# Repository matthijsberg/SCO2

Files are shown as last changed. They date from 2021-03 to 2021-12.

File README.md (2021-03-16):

# SCO2
The SCO2 is a small scale personal initiative to create CO2 sensors for the school my kids go to. Goal is to make the sensor:
 - Easy to use for teachers and kids
 - Show details for those interested
 - Looks good draws attention when needed
 - Solid to survive the challenging school environment
 - Decent but relatively cheap to build

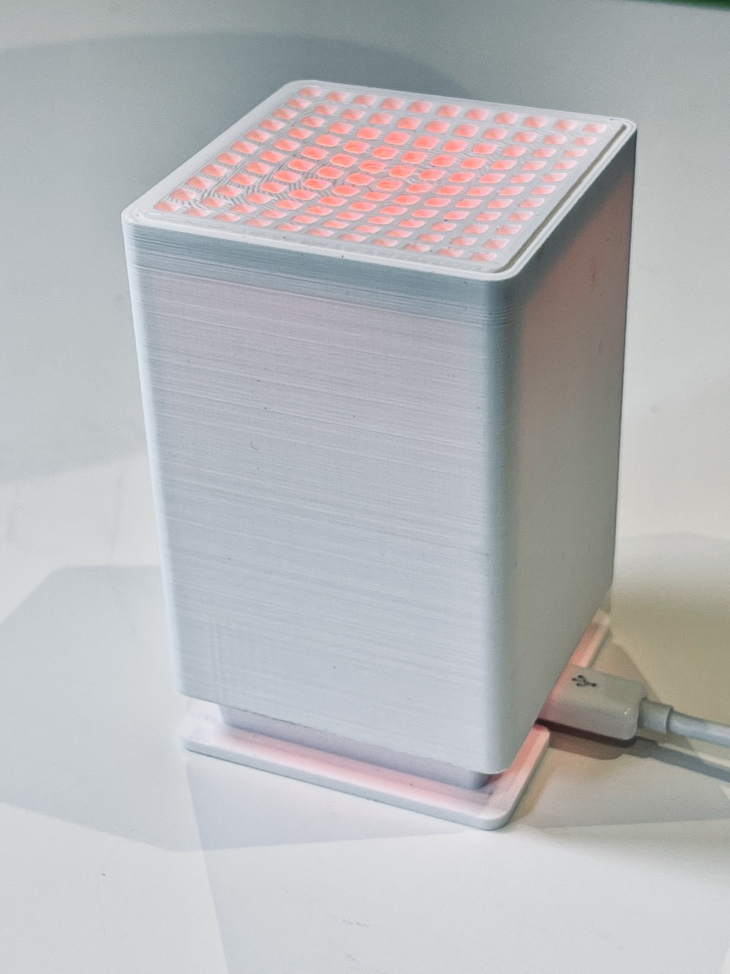
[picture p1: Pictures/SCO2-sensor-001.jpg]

 
# First Version
The first version is a completely home made device using some electronics, a soldering iron and a 3D printer (or an online 3D ordering service). 

## Components Used
The following components are used to build the sensor:
 - Wemos D1 Mini ESP board (this is the computer) https://www.wemos.cc/en/latest/d1/d1_mini.html
 - Sensirion SCD30 (This is the CO2 / Temp / Humidity sensor) https://www.sensirion.com/en/environmental-sensors/carbon-dioxide-sensors/carbon-dioxide-sensors-co2/
 - Wemos TGB Led Shield (to coler indicate air quality) https://www.wemos.cc/en/latest/d1_mini_shield/rgb_led.html
 - Some wires, shrinking tube and screws
 - 3D model existing out of 5 parts to put the sensor together. I fiddled around a bit with the tolerances to make the parts fit together nicely, so you might need to do so too. 

## Software used
I started out programming the thing myself in Visual code, that gives me great abilities but also is quite cumber stone since I'm not a programmer by trade. So I switched to ESPhome (https://esphome.io/). ESP Home abstracts the actual programming for you and all you need is a configuration file to tell the system what to compile for you. It can be ran alone or integrated into Home Assistant if you want an easy and comprehensive overview of all the sensors in for example your school. 

To be clear, the device can run alone without WiFi of back-end, but when you're up for it you can connect it and save the data in various systems. 

# 3D Files
The device exists out of 5 3D printer parts you can print on your own printer of via a service. You find the here, and assembling should be possible in one way only. :)

# Hardware assembly
Maybe I'll create a visual guide one day, but for now:
The hardware assembly consists out of 2 part, the D1 mini in the foot of the unit, and the sensor array holding the CO2 sensor and the LEDs. I build it like this so we can create new sensor array's later on and just swap them out. 

## ESP Board
This is the easy part, just solder a MALE pin header strip on the board ON ONE SIDE ONLY. We're only using the side of the board with the pin headers 5V to TX. once done, use 2 small screws to screw the board in the 3D printed bottom plate.

## Sensor Array
This is a bit trickier, since we need some wire and a couple of more connections. You need to:

 - 5V pin to 5V on the CO2 sensor and 5V on the LEDs
 - GND pin to GND on the CO2 sensor and GND on the LEDs
 - D4 on the board to D4 on the LEDs
 - D2 on the board to SDA on the CO2 sensor
 - D1 on the board to SCL on the CO2 sensor

# Software Installation
When you have all the parts in house and printed the enclosure make sure you have ESPHome running. For me it's part of my Home Assistant installation and for the school I build this for I have a Raspberry PI where I run HASSOS with ESP Home in. To get HASSIO running, please find the software and instructions here: https://www.home-assistant.io/installation/ . 

When you have ESPHome running as a Add-on:
 - Open the ESPHome interface
 - Connect the Device with a USB cable to your HA device
 - Open the "Secrets" File in the rop right corner to enter your passwords you will use (example in this github called secrets.yaml)
 - Create a new device, give it the right name straight away, but the rest of the information can be bogus IF you are using exactly the same ESP board
 - Now change the interface to upload the code to your device from over the air to the USB port (you can use OtA after initial flash)
 - Once created open the config by clicking "Edit" and past the example config from the repo into you config (sensor.yaml).
 - check if all the password and config options are correct and upload the file with "Upload"
 - See what happens. 
 - You can add the sensors to HA if you want under Integrations or under Device. 

Cheers! Drop me comments or improvements here in GitHub please. 

# Thank you!
 - Home Assistant for building great software that makes this easy to run a OS and a great Add-on ->
 - ESPHOME! This is amazing. Next gen programming language to make IOT easy IMHO. 
 - Autodesk for having a free edition of Fusion360
 - Ultimaker for providing the best slicer software for free to slice the 3D design and print them.

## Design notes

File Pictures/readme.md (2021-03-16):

Here are several picture of a finished sensor to give you an idea how to assemble it.

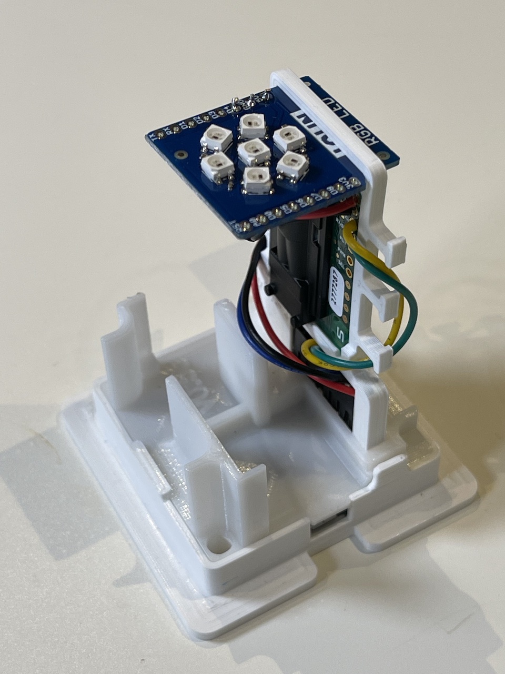
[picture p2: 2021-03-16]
Pictures/SCO2-sensor-008.jpg

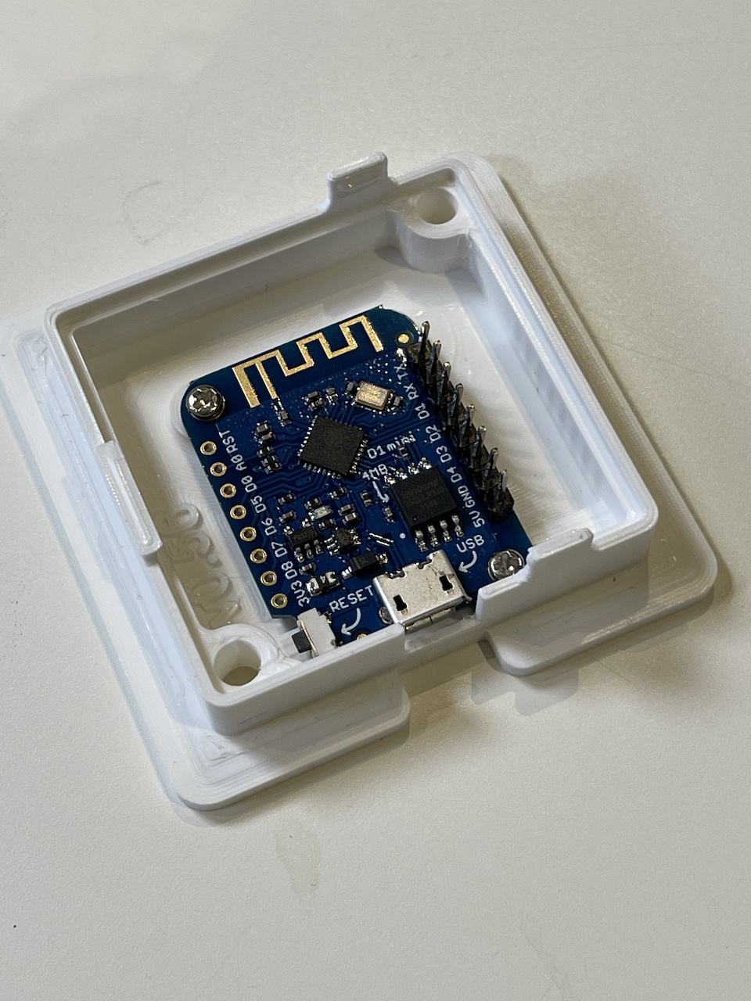
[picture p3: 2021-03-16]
Pictures/SCO2-sensor-004.jpg

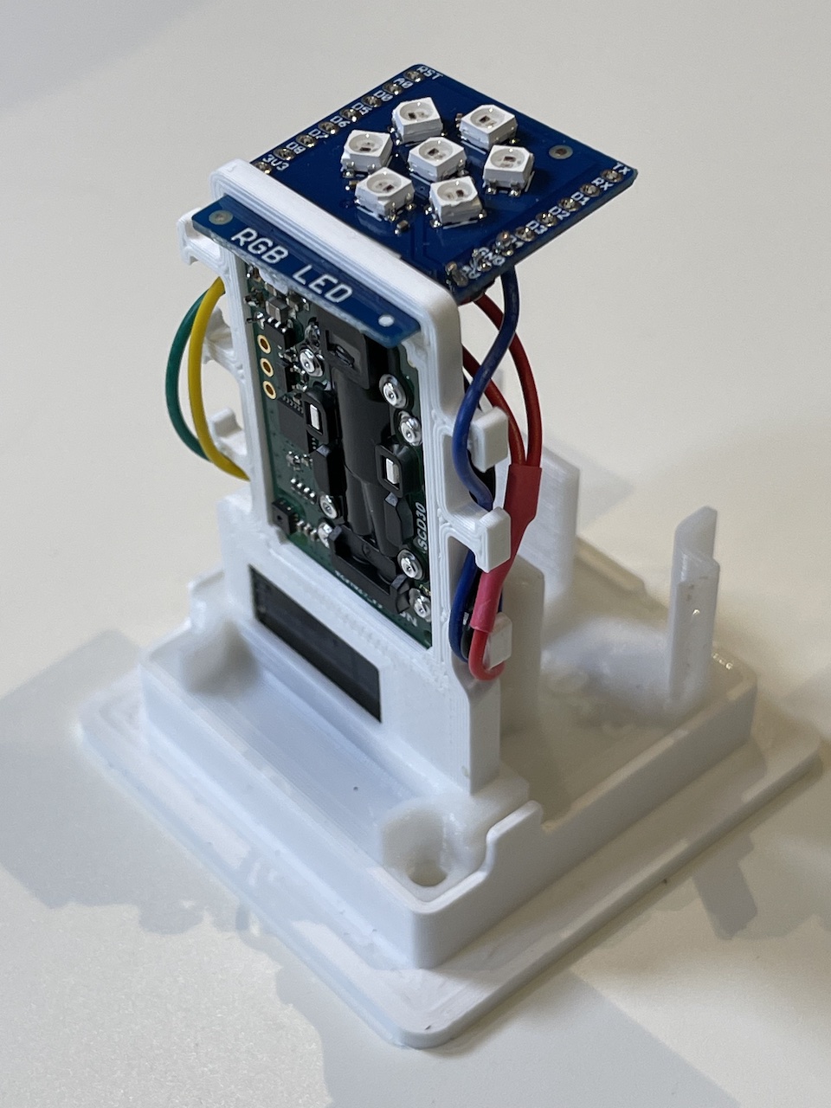
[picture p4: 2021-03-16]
Pictures/SCO2-sensor-007.jpg

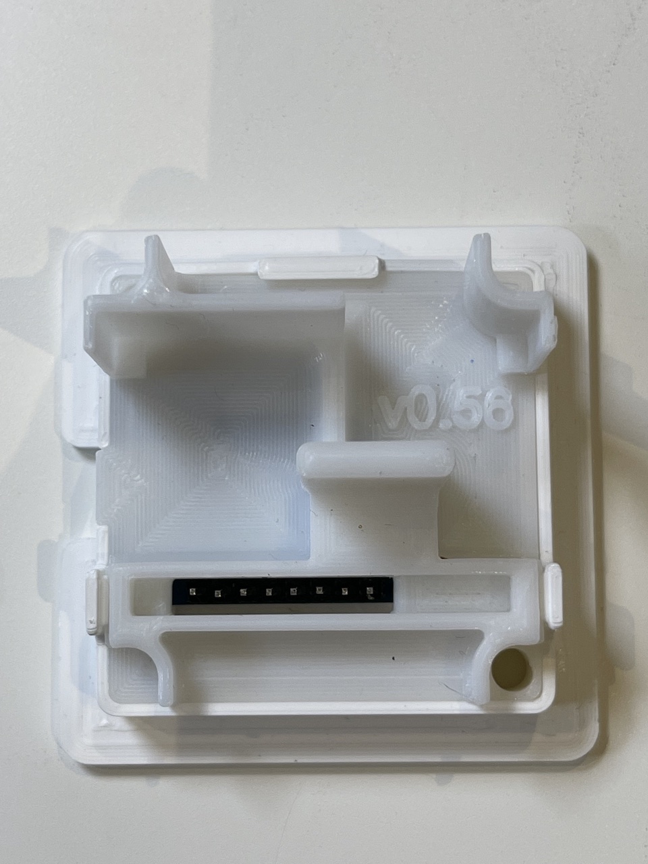
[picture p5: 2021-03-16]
Pictures/SCO2-sensor-005.jpg

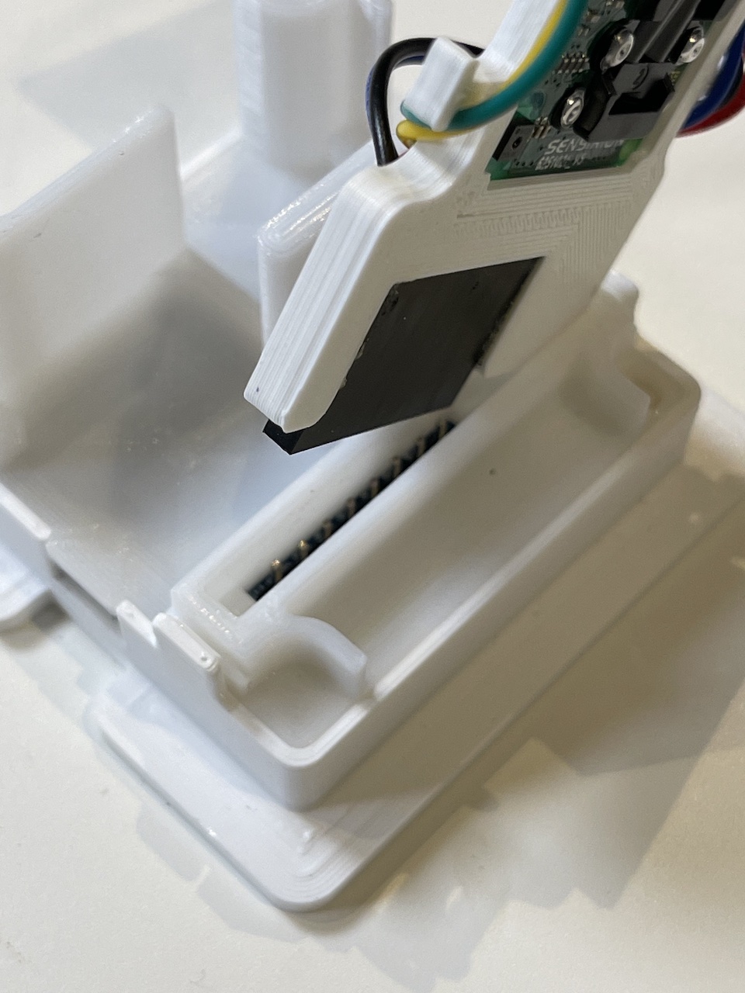
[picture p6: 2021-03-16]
Pictures/SCO2-sensor-003.jpg

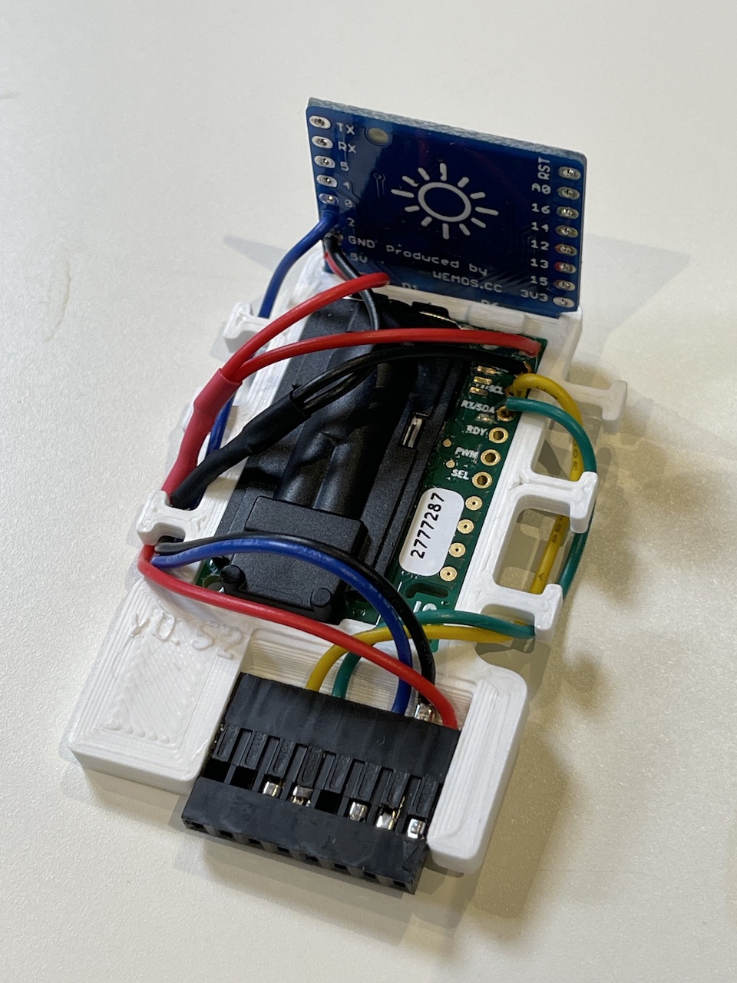
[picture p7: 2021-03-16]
Pictures/SCO2-sensor-006.jpg

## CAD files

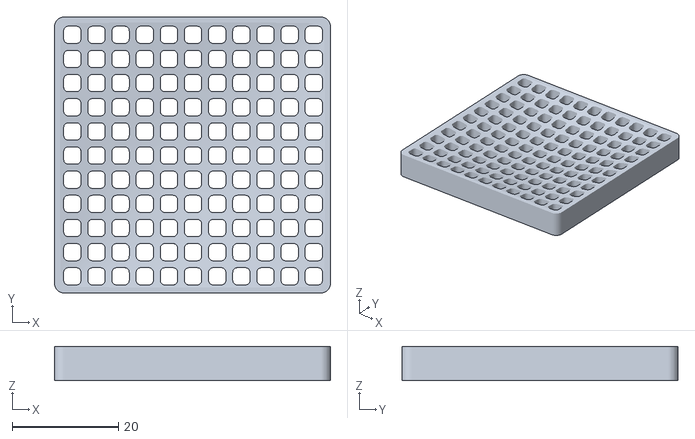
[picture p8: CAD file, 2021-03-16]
SCO2-TopGrid-v1.03.stl
51.8 x 51.8 x 6.47

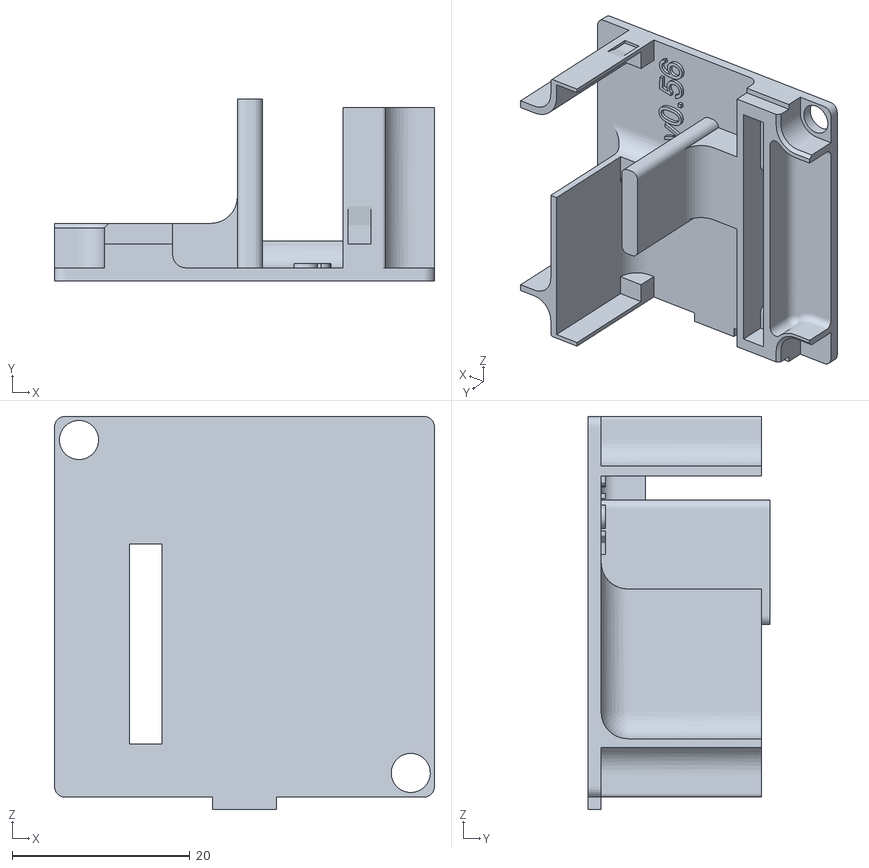
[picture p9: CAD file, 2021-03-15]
SCO2-BottomSensors-v1.02.stl
42.7 x 20.5 x 44.2

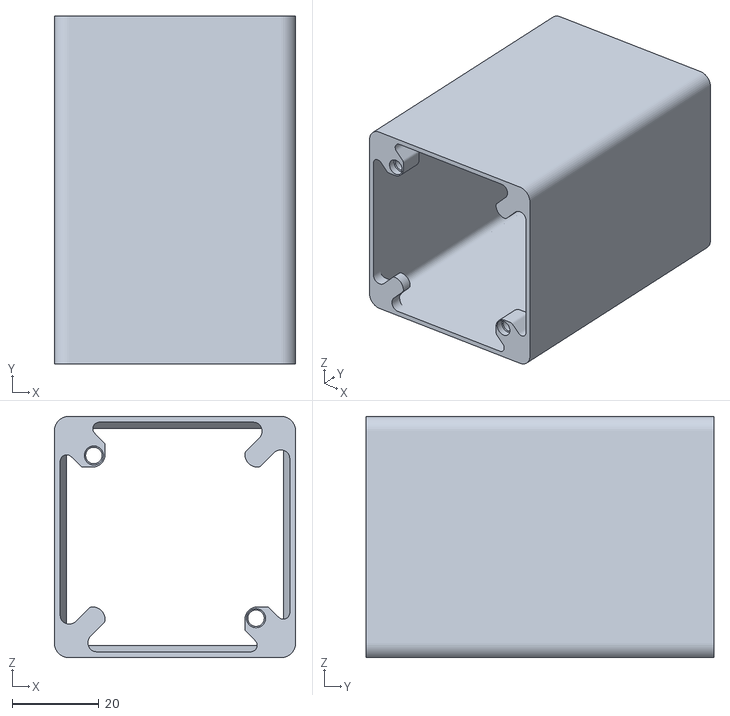
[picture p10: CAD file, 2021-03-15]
SCO2-Enclosure-v1.0.stl
55.5 x 80.0 x 55.5

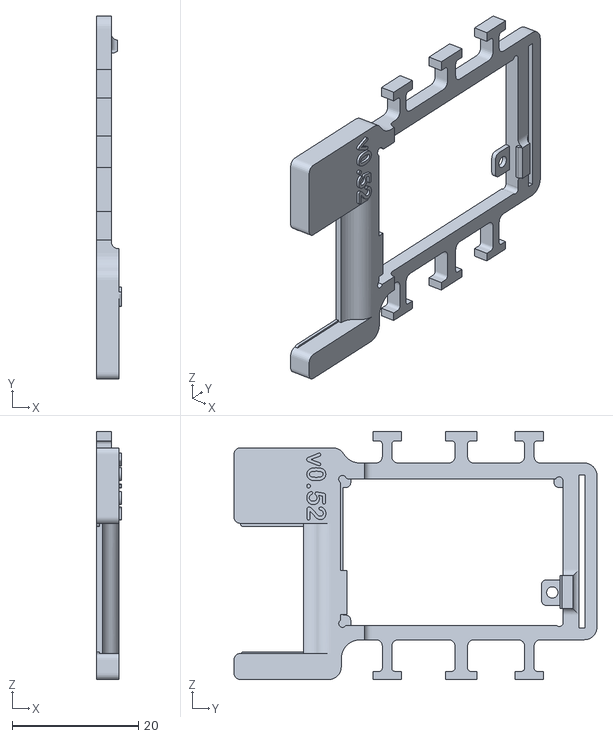
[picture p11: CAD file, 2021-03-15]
SCO2-SesorArray-v1.01.stl
3.90 x 57.5 x 39.3

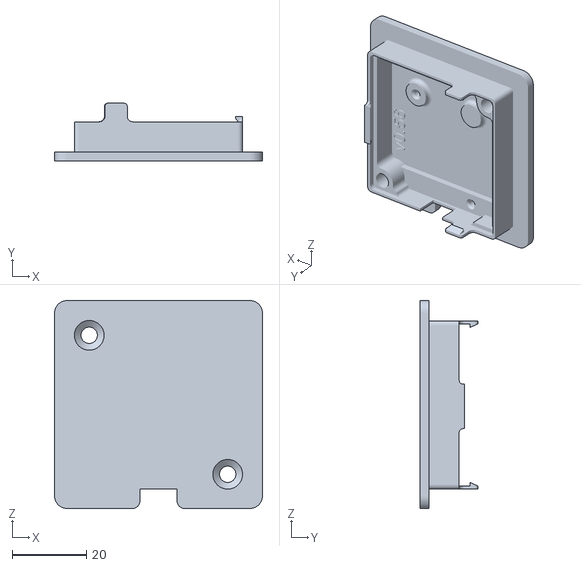
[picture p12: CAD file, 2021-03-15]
SCO2-BottomPlate-v1.01.stl
56.0 x 15.5 x 56.0

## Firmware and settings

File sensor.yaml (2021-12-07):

# SCO2 Project
# SCO2 Project
# Version 1.1
# The Variables for this device are here AND in the secrets file!
substitutions:
  device_name_friendly: 'Sensor Name'
  device_name: 'sensor' #DNS NAME!
  device_description: "SCO2 School CO2 sensor project. Batch 2. Software 1.1"
  wifi_fb_password: 'Tbs5ucnG24CMmj'
  scd30_temp_offset: '5.7'
#No changes after here required.


esphome:
  name: ${device_name}
  comment: ${device_description}
  project:
    name: "matthijs.sco2"
    version: "1.1.0"
  platform: ESP8266
  board: d1_mini
  on_boot:
    - light.turn_on:
        id: color_leds_id
        brightness: 65%
        red: 0%
        green: 0%
        blue: 100%
    - delay: 1s
    - light.control:
        id: color_leds_id
        effect: "Rainbow Effect"
    - delay: 10s
    - light.control:
        id: color_leds_id
        effect: "none"  

wifi:
  ssid: !secret wifi_ssid_iot
  password: !secret wifi_password_iot
  fast_connect: true

  # Enable fallback hotspot (captive portal) in case wifi connection fails
  ap:
    ssid: '${device_name_friendly} Fallback Hotspot'
    password: ${wifi_fb_password}

captive_portal:

# Example configuration entry
#debug:

# Logger (debug default)
logger:
  level: info

web_server:
  port: 80

# Enable Home Assistant API
api:
  password: !secret esphome_local
  reboot_timeout: 0s
  encryption: 
    key: !secret esphome_api_key
  id: device_name

ota:
  password: !secret esphome_local

i2c:
  sda: D2
  scl: D1
  scan: False
  id: bus_a
  frequency: 100kHz

time:
  - platform: homeassistant
    id: esp_time
  - platform: sntp
    id: ntp_time
    timezone: Europe/Amsterdam
#
#  - platform: homeassistant
#    id: homeassistant_time

sensor:
  - platform: scd30
    i2c_id: bus_a
    address: 0x61
    co2:
      name: '${device_name_friendly} CO2'
      #id: scd30_co2
      accuracy_decimals: 1
      on_value:
        then:
          lambda: !lambda |-
            auto call = id(color_leds_id).turn_on();
            static float red = 0.0;
            static float green = 0.0;
            static float blue = 0.0;             // x is sensor value input from ESP Home
            static float bright = 0.65;
            ESP_LOGD("main", "CO2 number is: %f", x);
            if (x < 800) {
              green = bright;
              red = 0.0;
              blue = 0.0;
              ESP_LOGD("main", "CO2 < 800 loop. Green: %f, red: %f, blue: %f", green, red, blue);
            } else if (x > 800 and x < 1500) { 
              red = ((x -800) / 700) * bright;
              green = (1 - ((x - 800) / 700)) * bright;
              blue = 0.0;
              ESP_LOGD("main", "CO2 800 - 1500 loop.. Green: %f, red: %f, blue: %f", green, red, blue);
            } else if (x > 1500 ){ 
              red = bright;
              green = 0.0;
              blue = 0.0;
              ESP_LOGD("main", "CO2 > 1500 loop. Green: %f, red: %f, blue: %f", green, red, blue);
            } 
            call.set_transition_length(1000); // in ms
            call.set_rgb(red, green, blue); // color, 1.0 is fully lit
            call.perform();
          # note that the logging in ESP Home debug console for RGB % is not correct, but the leds do give the right color.
    temperature:
      name: '${device_name_friendly} Temperature'
      #id: scd30_temperature
      accuracy_decimals: 1
    humidity:
      name: '${device_name_friendly} Humidity'
      #id: scd30_humidity
      accuracy_decimals: 1
    temperature_offset: ${scd30_temp_offset}
    update_interval: 10s
    altitude_compensation: 2m
    automatic_self_calibration: true

light:
  - platform: neopixelbus
    id: color_leds_id
    type: GRB
    method: ESP8266_UART1
    variant: WS2812X
    pin: D4
    num_leds: 7
    name: "${device_name_friendly} LED Light"
    restore_mode: ALWAYS_OFF
    effects:
      - addressable_rainbow:
          name: "Rainbow Effect"
          speed: 30
          width: 40

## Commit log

2021-03-15 Add files via upload
    Initial version of the 3D files of the sensors enclosure.
    [School Corona Sensor Project v2 v35.stl]
2021-12-07 Update sensor.yaml
    version 1.1 with some minor changes
